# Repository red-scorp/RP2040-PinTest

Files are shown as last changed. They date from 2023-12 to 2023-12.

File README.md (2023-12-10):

# RP2040-PinTest Project

The **RP2040-PinTest** project aims to display pin function with a simple LED.

## RP2040-PinTest Board

The **RP2040-PinTest** board is a simple 2-layer intended to test RP2040-Eins and RP2040-ProMini boards.

Preview:

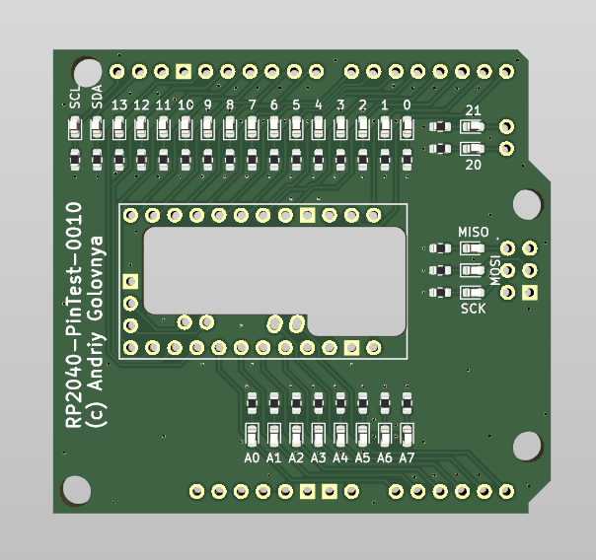
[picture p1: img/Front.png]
RP2040-PinTest Front preview


You can view the [Schematics in PDF format](doc/RP2040-PinTest.pdf) for detailed information.

Features:

- Uses Uno and ProMini footprints.
- Inidividual LED for each data pin.

## Version History

### v1.0b1

v1.0b1 board preview

Initial release for testing purposes.

## How to Help

Your contributions as code, resources, or finances are welcome! Please contact me directly via email at andriy.golovnya@gmail.com or through my [GitHub profile](https://github.com/red-scorp).

If you'd like to make a financial contribution, you can donate via [PayPal](http://paypal.me/redscorp) or [Ko-Fi](http://ko-fi.com/redscorp). Your support is greatly appreciated.

Thanks in advance!

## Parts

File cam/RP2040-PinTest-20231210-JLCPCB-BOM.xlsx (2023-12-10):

Qty | Designator | Footprint | JLCPCB Part# | Comment
29 | D13,D6,D1,D17,D2,D26,D11,D29,D22,D14,D15,D4,D5,D10,D25,D16,D18,D12,D9,D23,D28,D8,D27,D7,D21,D19,D3,D20,D24 | 0603 | C72038 | YELLOW
29 | R5,R25,R27,R20,R21,R3,R23,R29,R19,R24,R1,R12,R14,R2,R11,R4,R13,R7,R9,R22,R17,R6,R18,R10,R8,R26,R28,R15,R16 | 0603 | C23186 | 5k1

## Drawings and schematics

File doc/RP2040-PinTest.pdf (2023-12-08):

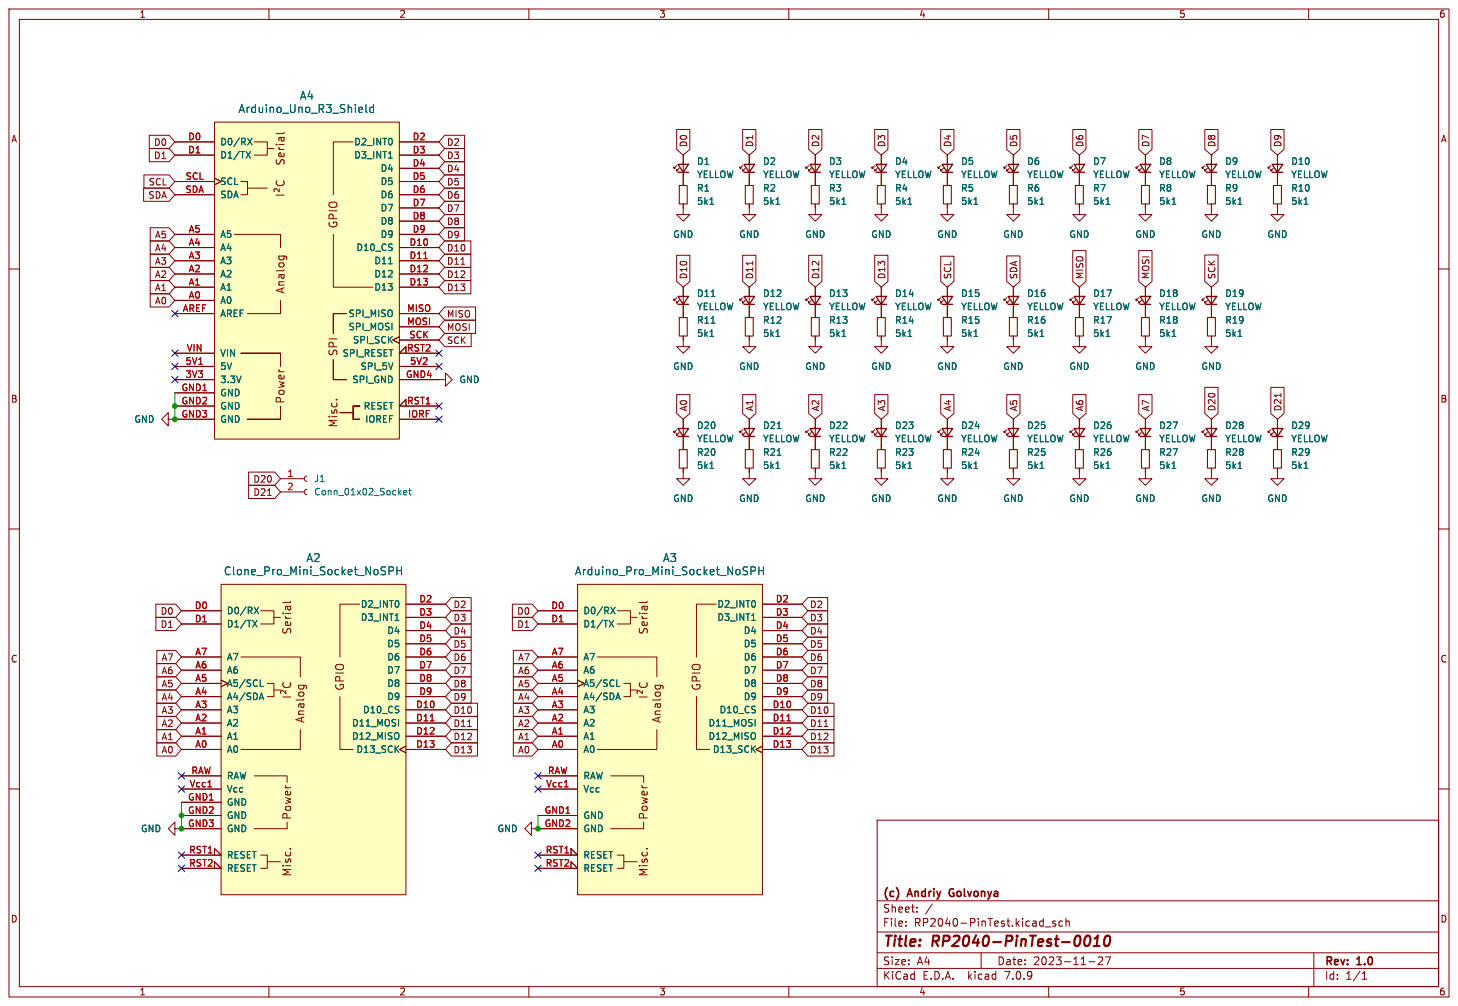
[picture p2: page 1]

File: RP2040-PinTest.kicad_sch Sheet: / (c) Andriy Golvonya

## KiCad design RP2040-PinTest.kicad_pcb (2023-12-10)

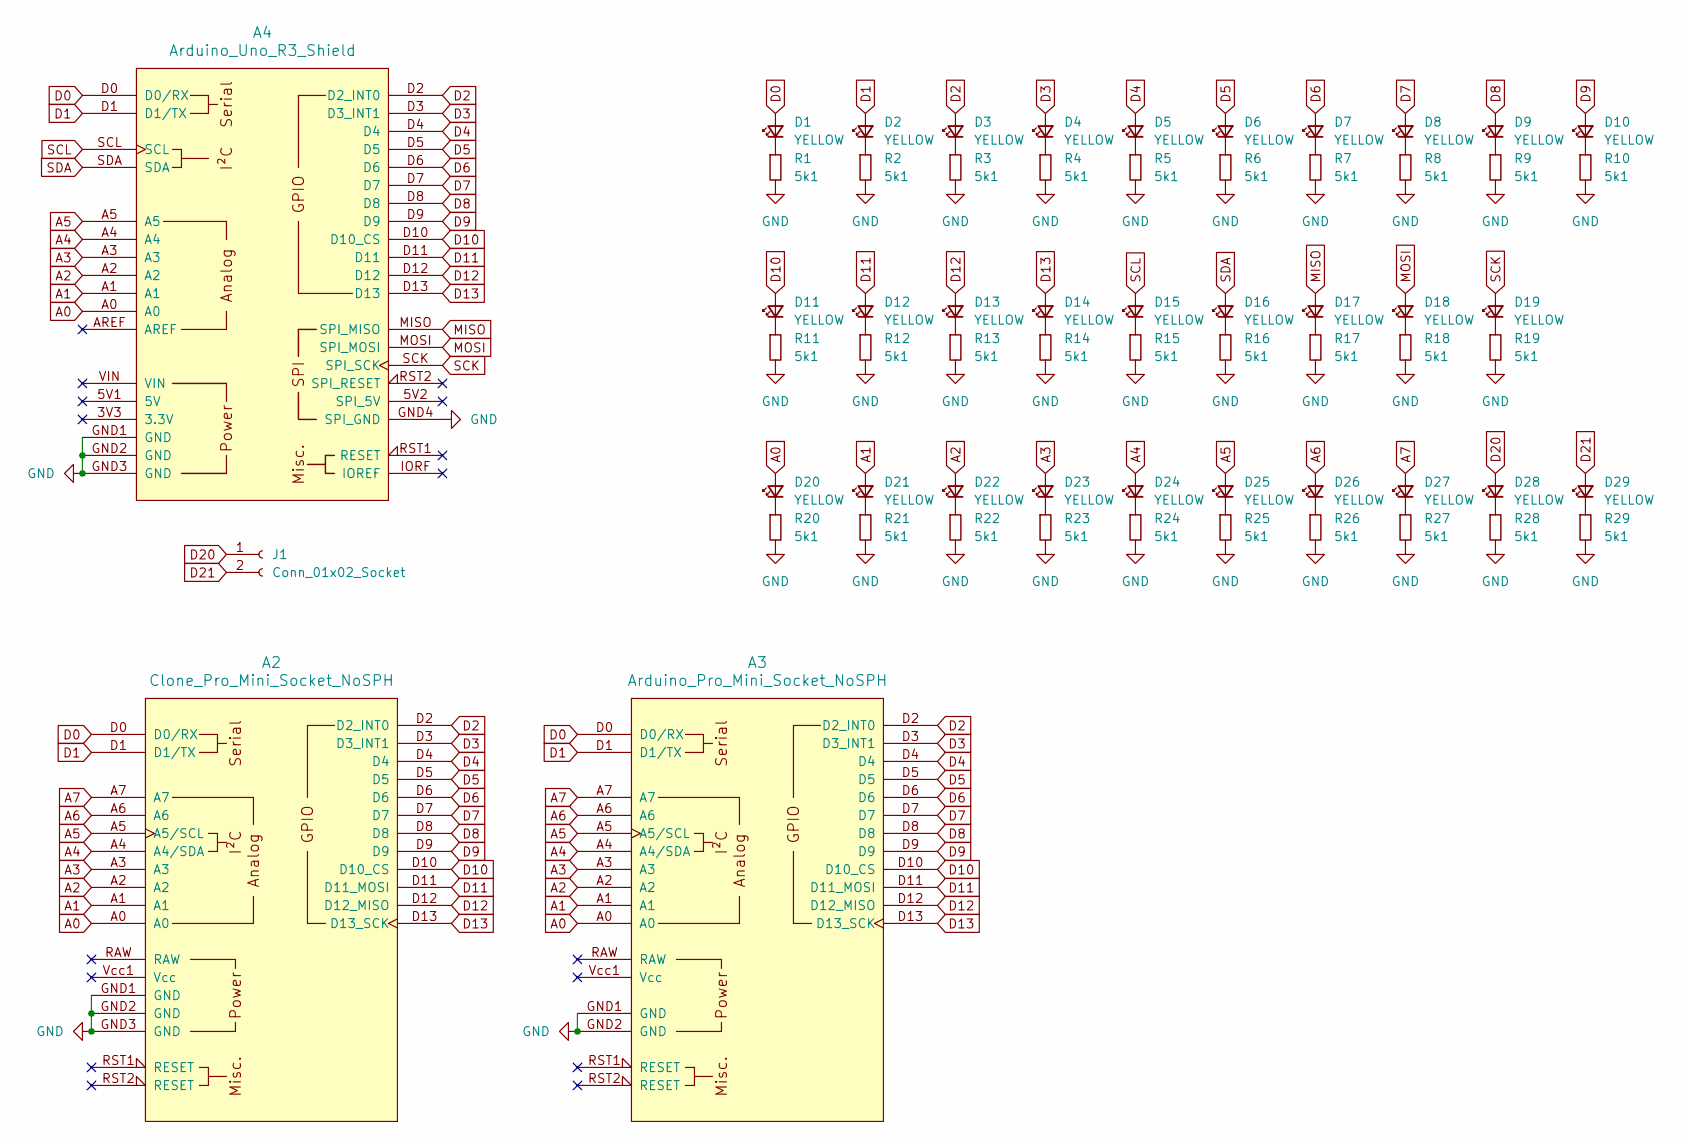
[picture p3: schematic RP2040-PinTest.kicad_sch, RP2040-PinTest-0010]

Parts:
A2: Clone_Pro_Mini_Socket_NoSPH
A3: Arduino_Pro_Mini_Socket_NoSPH
A4: Arduino_Uno_R3_Shield
D1, D2, D3, D4, D5, D6, D7, D8, D9, D10, D11, D12, D13, D14, D15, D16, D17, D18, D19, D20, D21, D22, D23, D24, D25, D26, D27, D28, D29: YELLOW; LED_0603_1608Metric
J1: Conn_01x02_Socket; PinSocket_1x02_P2.54mm_Vertical
R1, R2, R3, R4, R5, R6, R7, R8, R9, R10, R11, R12, R13, R14, R15, R16, R17, R18, R19, R20, R21, R22, R23, R24, R25, R26, R27, R28, R29: 5k1; R_0603_1608Metric

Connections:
A0: A2.A0, A3.A0, A4.A0, D20.2 (A)
A1: A2.A1, A3.A1, A4.A1, D21.2 (A)
A2: A2.A2, A3.A2, A4.A2, D22.2 (A)
A3: A2.A3, A3.A3, A4.A3, D23.2 (A)
A4: A2.A4 (A4/SDA), A3.A4 (A4/SDA), A4.A4, D24.2 (A)
A5: A2.A5 (A5/SCL), A3.A5 (A5/SCL), A4.A5, D25.2 (A)
A6: A2.A6, A3.A6, D26.2 (A)
A7: A2.A7, A3.A7, D27.2 (A)
D0: A2.D0 (D0/RX), A3.D0 (D0/RX), A4.D0 (D0/RX), D1.2 (A)
D1: A2.D1 (D1/TX), A3.D1 (D1/TX), A4.D1 (D1/TX), D2.2 (A)
D2: A2.D2 (D2_INT0), A3.D2 (D2_INT0), A4.D2 (D2_INT0), D3.2 (A)
D3: A2.D3 (D3_INT1), A3.D3 (D3_INT1), A4.D3 (D3_INT1), D4.2 (A)
D4: A2.D4, A3.D4, A4.D4, D5.2 (A)
D5: A2.D5, A3.D5, A4.D5, D6.2 (A)
D6: A2.D6, A3.D6, A4.D6, D7.2 (A)
D7: A2.D7, A3.D7, A4.D7, D8.2 (A)
D8: A2.D8, A3.D8, A4.D8, D9.2 (A)
D9: A2.D9, A3.D9, A4.D9, D10.2 (A)
D10: A2.D10 (D10_CS), A3.D10 (D10_CS), A4.D10 (D10_CS), D11.2 (A)
D11: A2.D11 (D11_MOSI), A3.D11 (D11_MOSI), A4.D11, D12.2 (A)
D12: A2.D12 (D12_MISO), A3.D12 (D12_MISO), A4.D12, D13.2 (A)
D13: A2.D13 (D13_SCK), A3.D13 (D13_SCK), A4.D13, D14.2 (A)
D20: D28.2 (A), J1.1
D21: D29.2 (A), J1.2
GND: A2.GND1 (GND), A2.GND2 (GND), A2.GND3 (GND), A3.GND1 (GND), A3.GND2 (GND), A4.GND1 (GND), A4.GND2 (GND), A4.GND3 (GND), A4.GND4 (SPI_GND), R1.2, R2.2, R3.2, R4.2, R5.2, R6.2, R7.2, R8.2, R9.2, R10.2, R11.2, R12.2, R13.2, R14.2, R15.2, R16.2, R17.2, R18.2, R19.2, R20.2, R21.2, R22.2, R23.2, R24.2, R25.2, R26.2, R27.2, R28.2, R29.2
MISO: A4.MISO (SPI_MISO), D17.2 (A)
MOSI: A4.MOSI (SPI_MOSI), D18.2 (A)
unnamed: D1.1 (K), R1.1
unnamed: D2.1 (K), R2.1
unnamed: D3.1 (K), R3.1
unnamed: D4.1 (K), R4.1
unnamed: D5.1 (K), R5.1
unnamed: D6.1 (K), R6.1
unnamed: D7.1 (K), R7.1
unnamed: D8.1 (K), R8.1
unnamed: D9.1 (K), R9.1
unnamed: D10.1 (K), R10.1
unnamed: D11.1 (K), R11.1
unnamed: D12.1 (K), R12.1
unnamed: D13.1 (K), R13.1
unnamed: D14.1 (K), R14.1
unnamed: D15.1 (K), R15.1
unnamed: D16.1 (K), R16.1
unnamed: D17.1 (K), R17.1
unnamed: D18.1 (K), R18.1
unnamed: D19.1 (K), R19.1
unnamed: D20.1 (K), R20.1
unnamed: D21.1 (K), R21.1
unnamed: D22.1 (K), R22.1
unnamed: D23.1 (K), R23.1
unnamed: D24.1 (K), R24.1
unnamed: D25.1 (K), R25.1
unnamed: D26.1 (K), R26.1
unnamed: D27.1 (K), R27.1
unnamed: D28.1 (K), R28.1
unnamed: D29.1 (K), R29.1
SCK: A4.SCK (SPI_SCK), D19.2 (A)
SCL: A4.SCL, D15.2 (A)
SDA: A4.SDA, D16.2 (A)

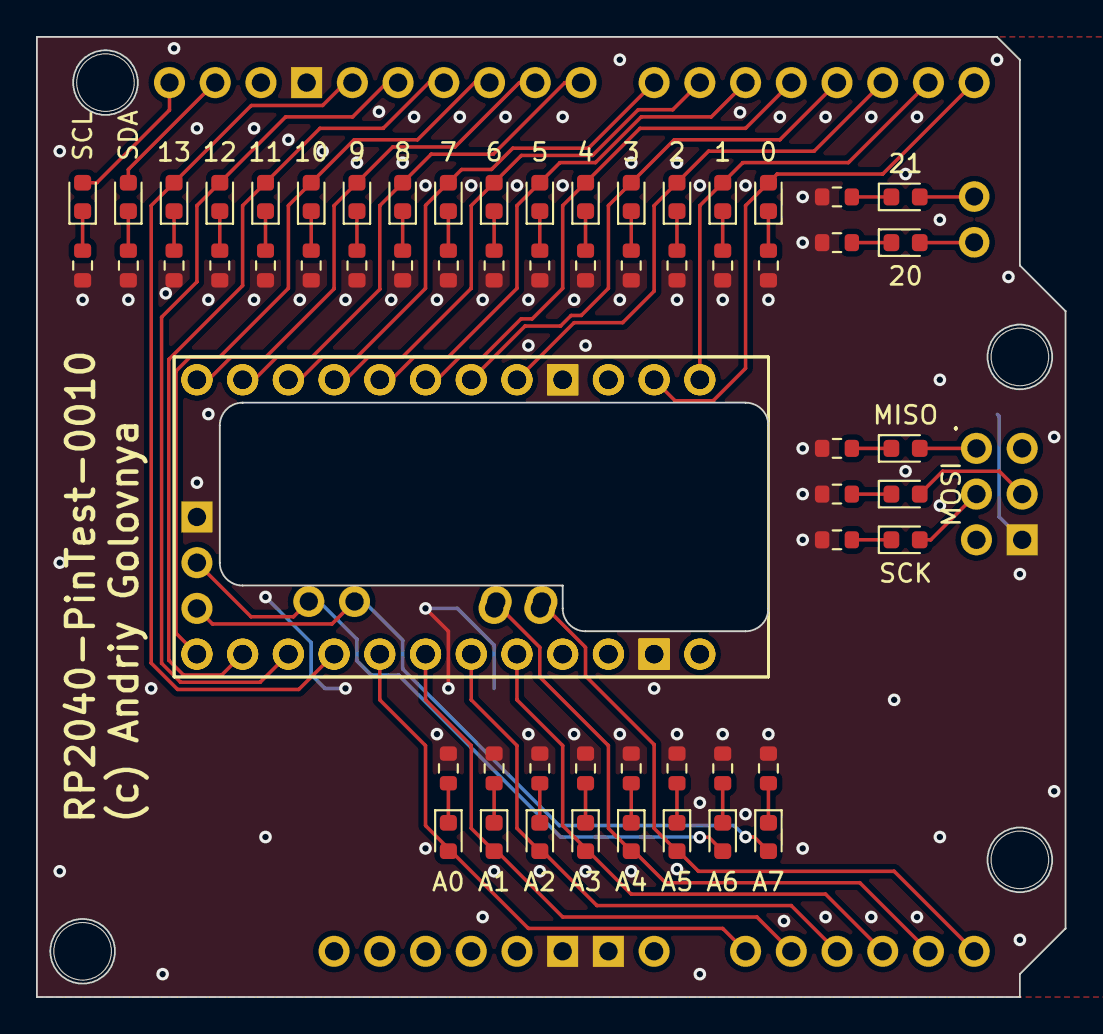
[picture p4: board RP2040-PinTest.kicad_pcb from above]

Board: 2 copper layers, 57.2 x 53.3 mm, 62 parts (1 on the bottom side), 59 nets.

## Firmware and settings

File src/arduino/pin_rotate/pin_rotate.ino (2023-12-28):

/**
 * @file pin_rotate.ino
 * @brief Arduino sketch to rotate a pin on and off
 *
 * This sketch will rotate all pins of the board on and off. The duration of each pin is 1 second.
 * Following boards are supported:
 * - Arduino Uno
 * - Arduino Leonardo
 * - Arduino M0
 * - Redscorp RP2040-Eins
 * - Redscorp RP2040-ProMini
 * 
 * @date 2023/11/28
 * @version 1.0.0
 */

#include <Arduino.h>

int pins_list[] =
#if defined(ARDUINO_AVR_UNO)
  {0, 1, 2, 3, 4, 5, 6, 7, 8, 9, 10, 11, 12, 13, A0, A1, A2, A3, A4, A5};  // Set the pins for Uno boards
#elif defined(ARDUINO_AVR_LEONARDO)
  {0, 1, 2, 3, 4, 5, 6, 7, 8, 9, 10, 11, 12, 13, A0, A1, A2, A3, A4, A5};  // Set the pins for Leonardo boards
#elif defined(ARDUINO_SAMD_ZERO)
  {0, 1, 2, 3, 4, 5, 6, 7, 8, 9, 10, 11, 12, 13, A0, A1, A2, A3, A4, A5};  // Set the pins for M0 boards
#elif defined(ARDUINO_REDSCORP_RP2040_EINS)
  {D0, D1, D2, D3, D4, D5, D6, D7, D8, D9, D10, D11, D12, D13, A0, A1, A2, A3, D18, D19, D20, D21};  // Set the pins for RP2040-Eins boards
#elif defined(ARDUINO_REDSCORP_RP2040_PROMINI)
  {D0, D1, D2, D3, D4, D5, D6, D7, D8, D9, D10, D11, D12, D13, A0, A1, A2, A3, D18, D19, D20, D21};  // Set the pins for RP2040-ProMini boards
#else
  #error "Unsupported board. Add conditions for the board in the code."
#endif

const int duration = 1000; // 1 second duration for each pin
const int pin_count = sizeof(pins_list) / sizeof(pins_list[0]); // Get the number of pins in the list

void setup() {
  Serial.begin();
  for (int i = 0; i < pin_count; i++) {
    int pin = pins_list[i]; // Get the pin number from the list
    pinMode(pin, OUTPUT);
    digitalWrite(pin, LOW);
  }
}

void loop() {
  for (int i = 0; i < pin_count; i++) {
    int pin = pins_list[i]; // Get the pin number from the list
    digitalWrite(pin, HIGH);
    Serial.print("pin: ");
    Serial.print(i);
    Serial.print(" - ");
    Serial.println(pin);
    delay(duration);
    digitalWrite(pin, LOW);
  }
}

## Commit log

2023-11-27 First basic design idea
    [RP2040-PinTest.kicad_pcb, RP2040-PinTest.kicad_sch]
2023-11-28 Added more pins
    [RP2040-PinTest.kicad_pcb, RP2040-PinTest.kicad_sch]
2023-11-28 Added LEDs and basic routing
    [RP2040-PinTest.kicad_pcb, RP2040-PinTest.kicad_sch]
2023-11-28 Added few traces and vias
    [RP2040-PinTest.kicad_pcb]
2023-11-28 Added few traces, vias and texts
    [RP2040-PinTest.kicad_pcb]
2023-11-29 Moved stuff around.
    [RP2040-PinTest.kicad_pcb]
2023-12-08 Updated file export parameters
    [RP2040-PinTest.kicad_pcb, RP2040-PinTest.kicad_sch]
2023-12-08 Generated PDF schematic
2023-12-10 Converted 0.4mm vias to 0.35mm
    [RP2040-PinTest.kicad_pcb]
2023-12-10 Generated BOM and CPL files
    [RP2040-PinTest-20231210-JLCPCB-BOM.xlsx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]
2023-12-10 Removed connector's 3D model from the 3D view
    [RP2040-PinTest.kicad_pcb]
